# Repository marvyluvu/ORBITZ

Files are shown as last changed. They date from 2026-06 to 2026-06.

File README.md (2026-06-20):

<h1 align="center">ORBITZ</h1>

ORBITZ (3)

<p align="center">
  <i>Desktop satellite, plane, and ISS tracker with a Console-style display and LED halo.</i>
</p>

---

##  1. What is ORBITZ

<p>
Orbit is a desktop satellite, plane, and ISS tracker with a radar-style display, LED halo, live ADS-B plane data, and GPS aware tracking
</p>

---

##  2. Why did I make it?

<p>
I personally love astronomy and being able to stargaze outside with the stars, but I could never catch a satellite or the ISS due to how fast they orbit, so when I heard of FALLOUT by hackclub, I saw this as the perfect opportunity to work and bring my idea to life!!
</p>

---

##  3. How does it work?

The brains of the operation is a Raspberry Pi Zero 2W. It:
-  Fetches TLEs from CelesTrak and uses Skyfield to compute live satellite and ISS passes.
-  Reads your location from GPSD (USB GPS) or falls back to a configured location.\
-  Receives live ADS‑B aircraft data either from a local RTL‑SDR + dump1090 or from the OpenSky API.
-  The display shows a radar view, the LED halo indicates visibility, and the buzzer alerts you before passes so you don’t miss them.

---

##  4.Hardware schematic

<p>
You can view the full schematic for the ORBITZ PCB below.
  </p>
  
ORBITZ schematic

---

##  5. How do you use it?

<p>
Plug it into usb c, Connect it to wifi, and it shows satellites and planes passing over your location
using the rotary dial and the button, you can scroll through targets and select them
</p>

If you plug in the USB GPS AND SDR DONGLE, Orbitz will automagically :
-  use gpsd for your location
-  use live ADS-B data from planes flying nearby for fully local tracking (or fall back to Opensky if no receiver is present)
---

## 6. Assembly:

1. First print the enclosure, and order all the items in the BOM.
2. Insert heat inserts in all screw standoffs.
3. insert battery into pcb.
4. insert pcb into enclosure, and make sure the battery is UNDER the pcb.
5. screw in pcb board.
6. attach screen with screws (MAKE SURE ITS ORIENTED PROPERLY with the row of pins pointing upwards)
7. insert joystick and wire to the pcb
8. cut rgb strip to size, then stick near the top of the enclosure.
9. wire rgb strip to pcb board.
10. Attach acrylic lid and back.
11. using super glue, attach the usb hub to the slot.
12. connect both the GPS and SDR dongle to the usb hub.
13. connect to power, flash firmware and enjoy!

## ASSEMBLED DESIGN 
Below is what your fully assembled design should look like.

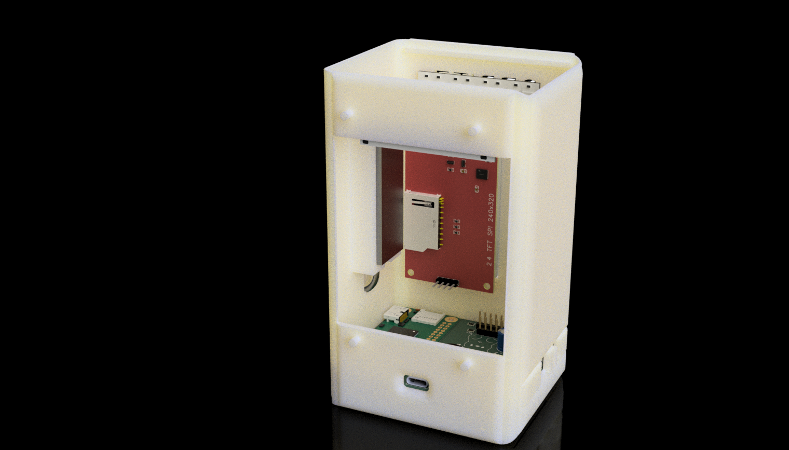
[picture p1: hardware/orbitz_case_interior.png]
ORBITZ enclosure interior
  

---

## 7. Firmware

There are two ways to run ORBITZ:

### 7.1 Desktop/mock firmware (no hardware required)

This runs the radar UI in a Pygame window on any PC or Pi, using mock drivers instead of the real display, LEDs, and buttons.

How to run (Windows / PowerShell):

1. Open a terminal in the `firmware` folder.
2. `python -m venv .venv`
3. `.\.venv\Scripts\Activate.ps1`
4. `pip install -r requirements.txt`
5. `python main.py`

Controls in mock mode:

- `m` + Enter: toggle between PLANES and SATS/ISS modes.
- `j` / `k` + Enter: move selection to next/previous target.
- `q` + Enter: quit.

### 7.2 Hardware firmware (Pi + PCB)

On the Pi Zero 2W with the ORBITZ PCB attached:

- The display shows the radar UI.
- The rotary encoder controls target selection.
- The encoder button toggles modes.
- The LED halo and buzzer reflect visibility/alerts.
- GPSD and dump1090/readsb are used automatically if available.

##  8. Images

<table>
  <tr>
    <td align="center">
      <strong>FINAL PCB SCREENSHOTS</strong><br><br>
      FINAL PCB SCREENSHOTS
    </td>
  </tr>
  <tr>
    <td align="center">
      <strong>PCB</strong><br><br>
      PCB
    </td>
  </tr>
  <tr>
    <td align="center">
      <strong>FINAL BUILD</strong><br><br>
      FINAL BUILD
    </td>
  </tr>
</table>

##  9. Bill of Materials (BOM)

The full detailed BOM is included in this repository:

- [`/ORBITZ_BILL_OF_MATERIALS.csv`](https://github.com/marvyluvu/ORBITZ/blob/main/hardware/BOM.csv)

You can open this file in Excel, Google Sheets, or any spreadsheet tool.
It includes part names, descriptions, quantities, prices, and direct purchase links.

Key components

| Product name | Description | Qty |
|---|---|-----|
| Raspberry Pi Zero 2W  | Main computer, runs satellite tracking software  | 1 |
| 2.4" NO TOUCH ILI9341| SPI LCD display for Orbitz radar UI | 1 |
| WS2812B LED STRIP | Internal RGB status lighting (1 m) | 1 |
| RTL‑SDR USB dongle | ADS‑B receiver for local aircraft (dump1090) | 1 |
| USB GPS dongle (VK‑172 or similar) | Provides live GPS position via GPSD | 1 |

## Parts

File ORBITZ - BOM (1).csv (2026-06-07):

Product name | Product description | Quantity | Product unit price | Product Total price | Product running total. | Product link
Raspberry Pi Zero 2W | Main computer, runs satellite tracking software | 1 | dh177.21 | dh177.21 | dh177.21 | https://www.amazon.ae/Raspberry-Pi-Zero-WH-Pre-Soldered/dp/B0DB2JBD9C?sbo=RZvfv%2F%2FHxDF%2BO5021pAnSA%3D%3D
2.4 NO TOUCH ILI9341 | display 2.4 NO TOUCH ILI9341 | 1 | dh30.85 | dh30.85 | dh208.06 | https://ar.aliexpress.com/item/1005006624846563.html?curPageLogUid=DswO6lagaiex
WS2812B 16bit-LED ring | RGB LED alert ring around display 16BIT | 1 | dh9.42 | dh9.42 | dh217.48 | https://ar.aliexpress.com/item/1005007503864128.html?curPageLogUid=HqRmNpZ1UxhF
TP4056 LiPo charger IC | Charges LiPo battery from USB-C 5PCS-TP4056 | 1 | dh4.50 | dh4.50 | dh221.98 | https://ar.aliexpress.com/item/32879731952.html?curPageLogUid=jYcawr7eByAd
MT3608 boost converter | Boosts 3.7V battery to 5V for Pi 10pcs | 1 | dh7.11 | dh7.11 | dh229.09 | https://ar.aliexpress.com/item/1005008853748359.html?curPageLogUid=QX7dJcdpuYRy
74AHCT125 level shifter | Converts 3.3V Pi signal to 5V for LEDs 5 pieces | 5 | dh1.37 | dh6.85 | dh230.46 | https://ar.aliexpress.com/item/1005007252553002.html?curPageLogUid=aYOZCnD8Argf
LiPo battery 2000mAh | Rechargeable battery for portable use 1 pcs | 1 | dh13.88 | dh13.88 | dh244.34 | https://ar.aliexpress.com/item/1005002919536938.html?curPageLogUid=qLuBs2UyvfCN
USB-C connector | Power input port 10 pcs | 1 | dh11.88 | dh11.88 | dh256.22 | https://ar.aliexpress.com/item/1005012104226670.html?curPageLogUid=KTklFuhYzL9x
JST PH 2.0 connector | Battery connection to PCB 10PCS | 1 | dh14.39 | dh14.39 | dh270.61 | https://ar.aliexpress.com/item/1005008142013739.html?curPageLogUid=xpRA092D5GlK
Rotary encoder EC11 | Scroll and select satellites 5pcs | 1 | dh12.83 | dh12.83 | dh283.44 | https://www.aliexpress.com/item/1005010452780913.html
Tactile push button | User input buttons 6x6x10mm | 1 | dh7.68 | dh7.68 | dh291.12 | https://ar.aliexpress.com/item/1005005758810513.html?curPageLogUid=yM7oY3n3MmHz
Piezo buzzer passive | Audio alert on satellite pass 10pcs | 1 | dh3.75 | dh3.75 | dh294.87 | https://ar.aliexpress.com/item/1005009532534215.html?curPageLogUid=KDV5pBV1Jt8v
RESISTOR KIT | Various resistors for pull-ups and current limiting 1206 80ValuesX25PCS | 1 | dh12.07 | dh12.07 | dh303.19 | https://ar.aliexpress.com/item/1005010779044079.html?curPageLogUid=fLpaeyL95z3P
Resistor 5.1kΩ 1206 |  | 2 | dh0.00 | dh0.00 | dh303.19
Resistor 2kΩ 1206 |  | 1 | dh0.00 | dh0.00 | dh303.19
Resistor 1kΩ 1206 |  | 2 | dh0.00 | dh0.00 | dh303.19
Resistor 10kΩ 1206 |  | 6 | dh0.00 | dh0.00 | dh303.19
Resistor 68kΩ 1206 |  | 1 | dh0.00 | dh0.00 | dh303.19
Resistor 10kΩ 1206 |  | 1 | dh0.00 | dh0.00 | dh303.19
Resistor 100Ω 1206 |  | 1 | dh0.00 | dh0.00 | dh303.19
Resistor 470Ω 1206 |  | 1 | dh0.00 | dh0.00 | dh303.19
Resistor 33Ω 1206 |  |  | dh0.00 | dh0.00 | dh303.19
Capacitor 100nF 1206 | Decoupling and filtering capacitors 1206 36values | 6 | dh25.73 | dh154.38 | dh328.92 | https://ar.aliexpress.com/item/1005006133726252.html?curPageLogUid=mtzgAqImZ92X
Capacitor 10µF 1206 |  | 1 |  | dh0.00 | dh328.92
Capacitor 22µF 1206 |  | 1 |  | dh0.00 | dh328.92
Capacitor 1000µF THT | Power supply bulk capacitor 25V1000UF 10PCS | 1 | dh3.37 | dh3.37 | dh332.29 | https://ar.aliexpress.com/item/1005005557021801.html?curPageLogUid=CyEONsUD6932
Inductor 4.7µH 1206 | MT3608 boost converter inductor 1206 4.7UH | 1 | dh3.75 | dh3.75 | dh336.04 | https://ar.aliexpress.com/item/1005004840798951.html?curPageLogUid=lhX8o1zcZvJs
LED red 1206 | Charge status indicator 1206 SMD LED | 1 | dh16.37 | dh16.37 | dh352.41 | https://ar.aliexpress.com/item/1005010305932502.html?curPageLogUid=1v1DsI2EMYpt
female pin header strip | Pi Zero socket 2x20p | 1 | dh8.21 | dh8.21 | dh360.62 | https://ar.aliexpress.com/item/32960673769.html?curPageLogUid=vMd8AdRMZrj1
male pin header strip | Breakable header for display/LED/battery connectors 10pcs 40p | 1 | dh27.13 | dh27.13 | dh387.75 | https://ar.aliexpress.com/item/1005011692961056.html?curPageLogUid=xRNMDLbYc9P6
solder paste |  | 1 | dh20.21 | dh20.21 | dh407.96 | https://ar.aliexpress.com/item/1005009438270413.html?curPageLogUid=sJOSY5CdizGG
jumper cable set | for connecting the screen ,leds and encoder 120pcs Flexible Kit 10cm | 1 | dh30.61 | dh30.61 | dh438.57 | https://ar.aliexpress.com/item/1005003219096948.html?curPageLogUid=dKpcIBUo1wTC
Custom PCB | ORBITZ custom carrier board ( with shipping ) | 1 | dh94.71 | dh94.71 | dh533.28 | JLCPCB
 |  |  |  |  | dh533.28
 |  |  |  | ALIXPRESS SHIPPING | 107.44
 |  |  |  | TOTAL FOR EVERYTHING | dh640.72
 |  |  |  | IN USD | 174.46$

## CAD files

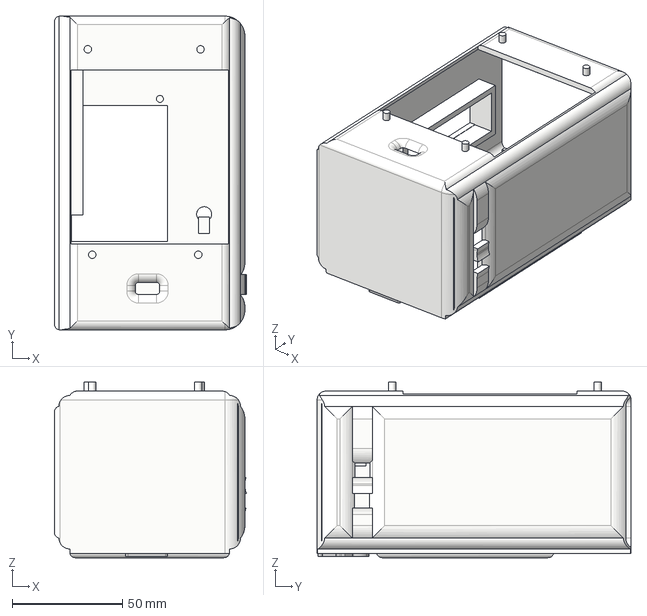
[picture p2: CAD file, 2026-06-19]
enclosure/enclosure.step
86.9 x 142.0 x 79.4 mm

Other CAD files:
enclosure/enclosure.f3d
enclosure/enclosure.stl

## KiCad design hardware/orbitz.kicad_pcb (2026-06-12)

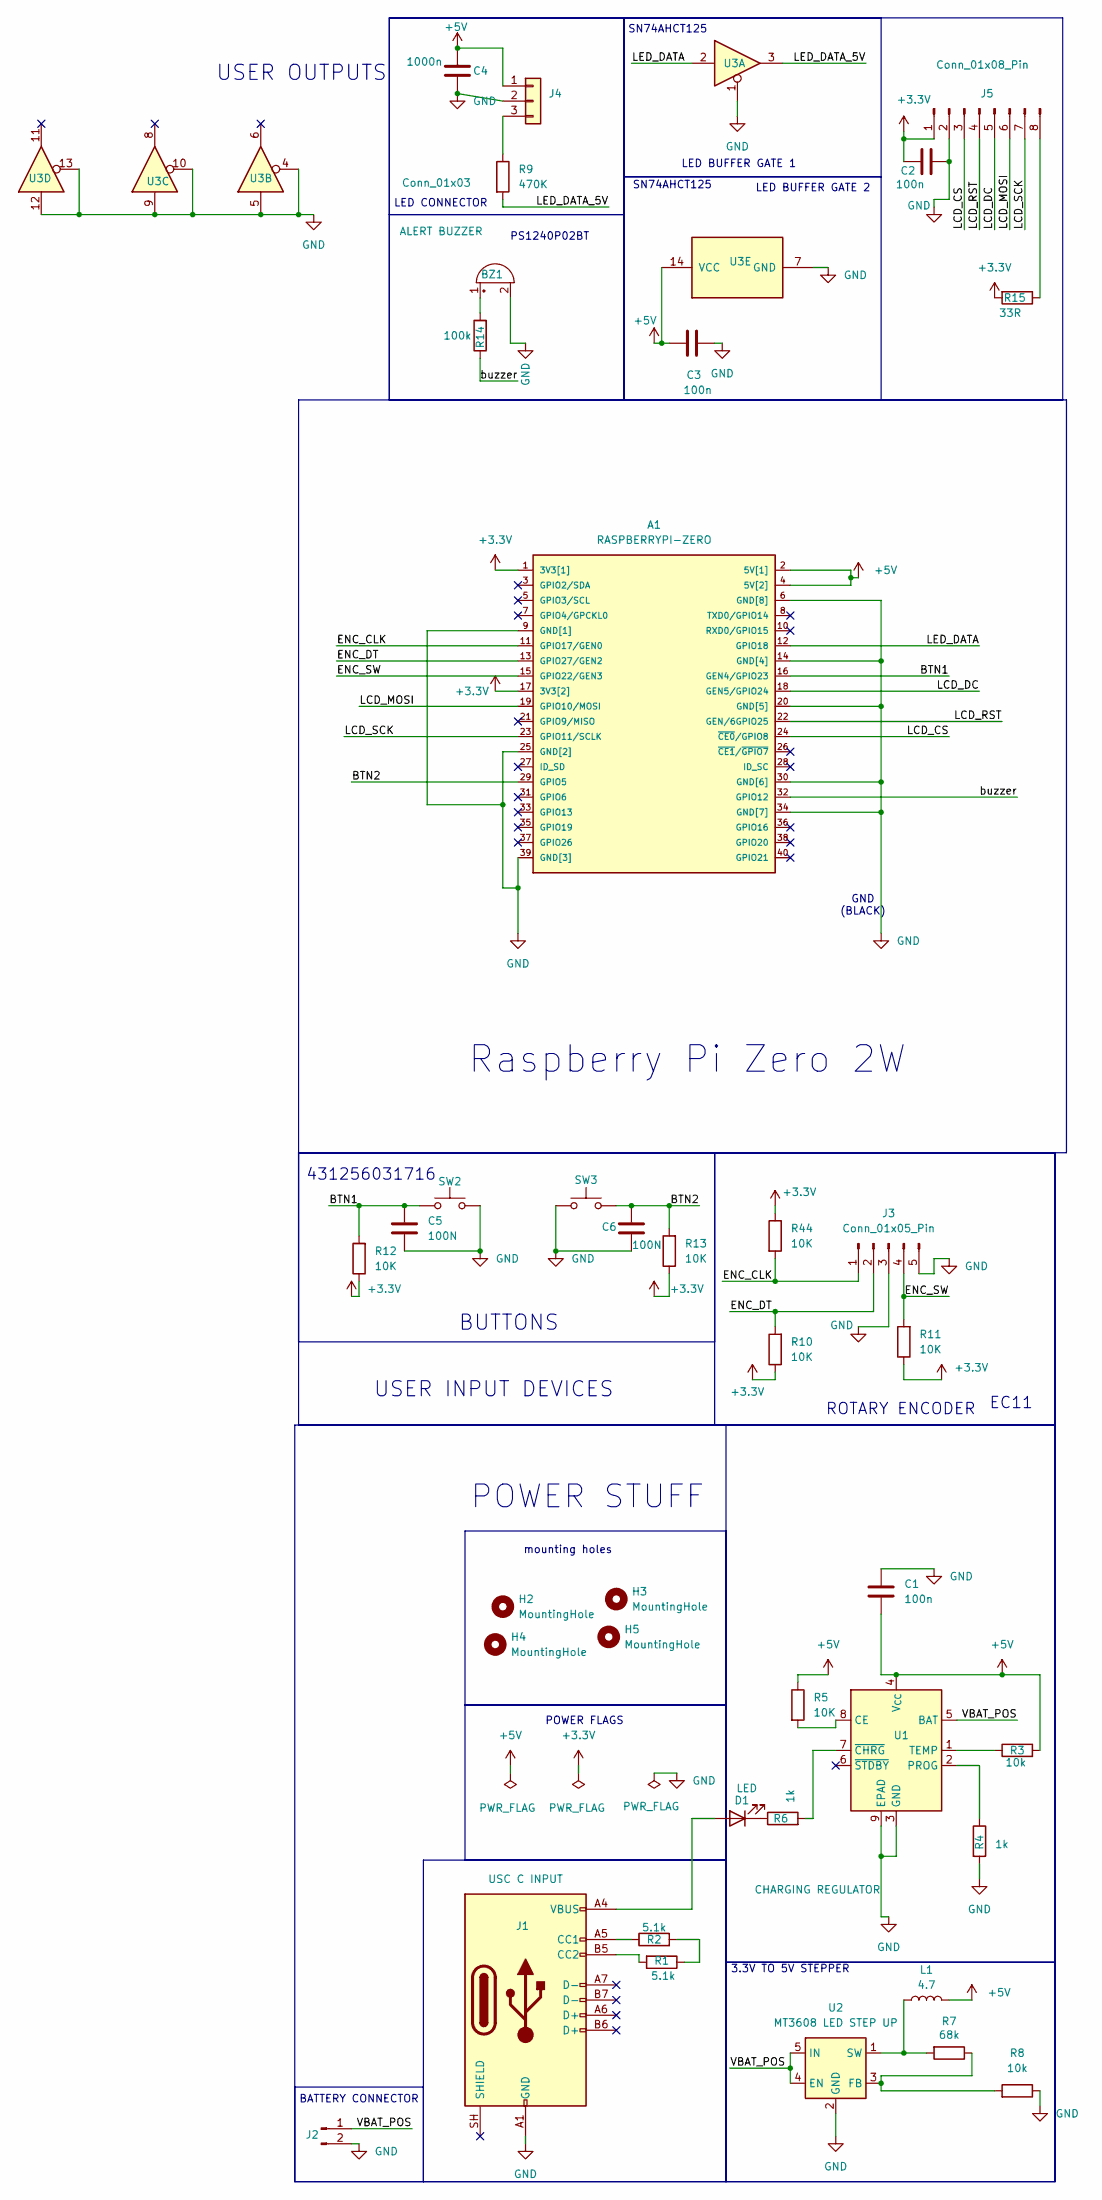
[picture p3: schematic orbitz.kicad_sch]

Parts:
A1: RASPBERRYPI-ZERO; RASPBERRYPI-ZERO_RPI-ZERO
BZ1: ALERT BUZZER; Buzzer_TDK_PS1240P02BT_D12.2mm_H6.5mm
C1, C2, C3: 100n; C_1206_3216Metric
C4: 1000n; CP_Radial_D8.0mm_P3.50mm
C5, C6: 100N; C_1206_3216Metric
D1: LED; LED_1206_3216Metric
H2, H3, H4, H5: MountingHole; MountingHole_3.2mm_M3
J1: USC C INPUT; USB_C_Receptacle_HRO_TYPE-C-31-M-12
J2: batt connector; JST_PH_S2B-PH-K_1x02_P2.00mm_Horizontal
J3: Conn_01x05_Pin; PinHeader_1x05_P2.54mm_Vertical
J4: Conn_01x03; PinHeader_1x03_P2.54mm_Vertical
J5: Conn_01x08_Pin; PinHeader_1x08_P2.54mm_Vertical
L1: 4.7; L_0805_2012Metric
R1, R2: 5.1k; R_1206_3216Metric
R3, R8: 10k; R_1206_3216Metric
R4, R6: 1k; R_1206_3216Metric
R5, R10, R11, R12, R13, R44: 10K; R_1206_3216Metric
R7: 68k; R_1206_3216Metric
R9: 470K; R_1206_3216Metric
R14: 100k; R_1206_3216Metric
R15: 33R; R_1206_3216Metric
SW2: selection button; SW_Tactile_SPST_Angled_PTS645Vx31-2LFS
SW3: selection button 2; SW_Tactile_SPST_Angled_PTS645Vx31-2LFS
U1: CHARGING REGULATOR; SOIC-8-1EP_3.9x4.9mm_P1.27mm_EP2.41x3.3mm_ThermalVias
U2: MT3608 LED STEP UP; SOT-23-6
U3: 74AHCT125; SOIC-14_3.9x8.7mm_P1.27mm

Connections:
+3.3V: A1.1 (3V3[1]), A1.17 (3V3[2]), C2.1, J5.1, R10.1, R11.1, R12.1, R13.1, R15.2, R44.1
+5V: A1.2 (5V[1]), A1.4 (5V[2]), C1.2, C3.1, C4.1, J4.1, L1.2, R3.2, R5.1, U1.4 (V_{CC}), U3.14 (VCC)
/BTN1: A1.16 (GEN4/GPIO23), C5.1, R12.2, SW2.1
/BTN2: A1.29 (GPIO5), C6.1, R13.2, SW3.2
/ENC_CLK: A1.11 (GPIO17/GEN0), J3.1, R44.2
/ENC_DT: A1.13 (GPIO27/GEN2), J3.2, R10.2
/ENC_SW: A1.15 (GPIO22/GEN3), J3.4, R11.2
/LCD_CS: A1.24 (~CE0/GPIO8), J5.3
/LCD_DC: A1.18 (GEN5/GPIO24), J5.5
/LCD_MOSI: A1.19 (GPIO10/MOSI), J5.6
/LCD_RST: A1.22 (GEN/6GPIO25), J5.4
/LCD_SCK: A1.23 (GPIO11/SCLK), J5.7
/LED_DATA: A1.12 (GPIO18), U3.2
/LED_DATA_5V: R9.2, U3.3
/VBAT_POS: J2.1, U1.5 (BAT), U2.4 (EN), U2.5 (IN)
/buzzer: A1.32 (GPIO12), R14.1
GND: A1.6 (GND[8]), A1.9 (GND[1]), A1.14 (GND[4]), A1.20 (GND[5]), A1.25 (GND[2]), A1.30 (GND[6]), A1.34 (GND[7]), A1.39 (GND[3]), BZ1.2 (-), C1.1, C2.2, C3.2, C4.2, C5.2, C6.2, J1.A1 (GND), J1.A12 (GND), J1.B1 (GND), J1.B12 (GND), J2.2, J3.3, J3.5, J4.2, J5.2, R4.2, R8.1, SW2.2, SW3.1, U1.3 (GND), U1.9 (EPAD), U2.2 (GND), U3.1, U3.4, U3.5, U3.7 (GND), U3.9, U3.10, U3.12, U3.13
unnamed: BZ1.1 (+), R14.2
unnamed: D1.2 (A), J1.A4 (VBUS), J1.A9 (VBUS), J1.B4 (VBUS), J1.B9 (VBUS)
unnamed: D1.1 (K), R6.1
unnamed: J1.A5 (CC1), R2.1
unnamed: J1.B5 (CC2), R1.2
unnamed: J4.3, R9.1
unnamed: J5.8, R15.1
unnamed: R1.1, R2.2
unnamed: R5.2, U1.8 (CE)
unnamed: R4.1, U1.2 (PROG)
unnamed: R3.1, U1.1 (TEMP)
unnamed: R6.2, U1.7 (~CHRG)
unnamed: R7.1, R8.2, U2.3 (FB)
unnamed: L1.1, R7.2, U2.1 (SW)

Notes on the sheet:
LED BUFFER GATE 1
USER INPUT DEVICES
SN74AHCT125
LED CONNECTOR
POWER FLAGS
3.3V TO 5V STEPPER
EC11
GND (BLACK)
431256031716
POWER STUFF
BUTTONS
PS1240P02BT
Raspberry Pi Zero 2W
ROTARY ENCODER
mounting holes
USER OUTPUTS
BATTERY CONNECTOR
LED BUFFER GATE 2

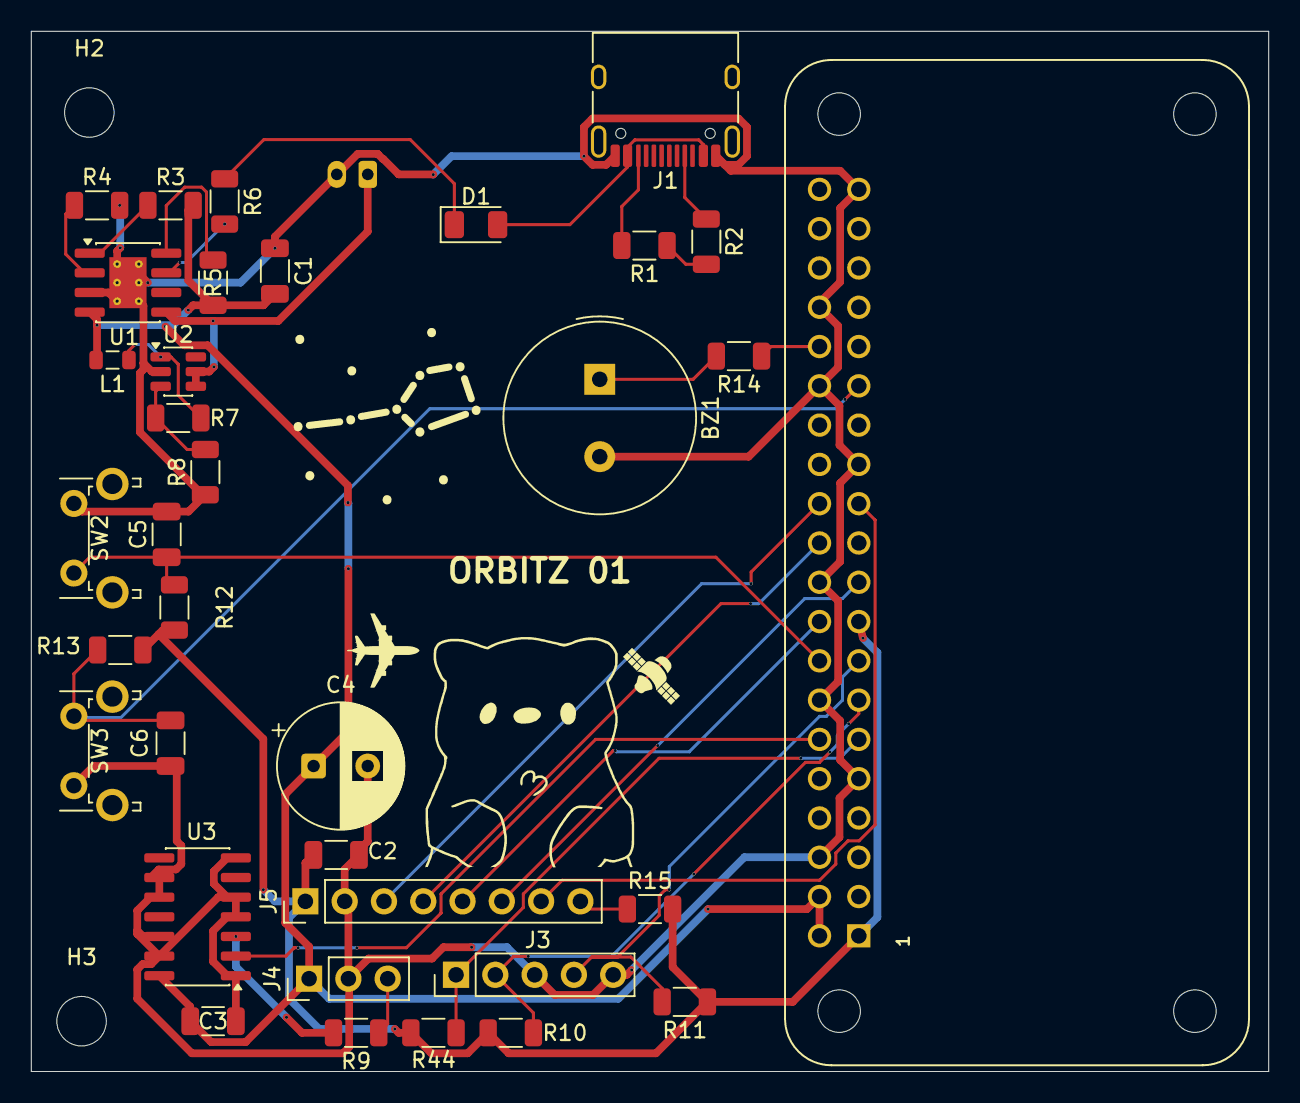
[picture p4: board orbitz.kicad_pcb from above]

Board: 2 copper layers, 80.0 x 67.2 mm, 38 parts (1 on the bottom side), 31 nets.

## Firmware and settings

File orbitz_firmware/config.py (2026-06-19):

#SCREEN PINS

LCD_MOSI = 10
LCD_SCK = 11
LCD_CS = 8
LCD_DC = 24
LCD_RST = 25
LCD_WIDTH = 240
LCD_HEIGHT = 320
LCD_SPI_BUS = 0
LCD_SPI_DEVICE = 0

#ROTARY ENCODER

ENC_CLK = 17
ENC_DT = 27
ENC_SW = 22


#BUTTONS
BTN1 = 23
BTN2 = 5

#ALERTING

LED_DATA = 18
LED_COUNT = 8 #CHANGE IT TO YOUR ACTUAL LED COUNT 
BUZZER_PINS = 12

# Update these if you move the device

OBSERVER_LAT = 25.3463
OBSERVER_LON = 55.4209
OBSERVER_ELEV= 0

# OpenSky planes API
PLANES_API_URL = "https://opensky-network.org/api/states/all" 
PLANES_API_TIMEOUT = 1.5
PLANES_BBOX_DEGREES = 1.0 
PLANES_MAX_RANGE_KM = 400.0

# Local dump1090 /ADS-B
PLANES_LOCAL_URL = "http://pi/dump1090/data/aircraft.json" #PLACEHOLDER!!!!

PLANES_LOCAL_TIMEOUT = 0.3  

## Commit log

2026-06-07 Rename ORBITZ - BOM (1).csv to ORBITZ - BILL OF MATERIALS.csv
    [ORBITZ - BILL OF MATERIALS.csv]
2026-06-07 Create PCB FILES
2026-06-14 Rename ORBITZ - BOM (2).csv to BOM/ORBITZ - BILL OF MATERIALS.csv
    [ORBITZ - BILL OF MATERIALS.csv]
2026-06-20 Fix formatting issue in assembly instructions
